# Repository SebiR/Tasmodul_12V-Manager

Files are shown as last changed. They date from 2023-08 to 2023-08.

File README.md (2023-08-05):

# 12V Power Management
A Tasmota compatible power selector for Caravans including automatic power source switching between on-board battery, car power and a mains PSU.
A INA226 measures the output voltage and current, the presence of the power sources are also available on GPIOs.

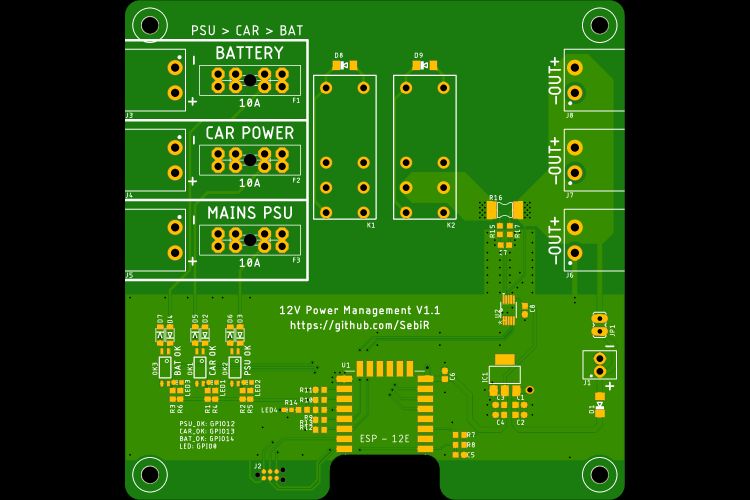
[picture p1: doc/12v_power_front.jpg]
12V Power


## Features
* Up to 15A (10A nom.)
* Fused inputs
* Current and voltage measurement
* Automatic source switching with priorities (hard-wired)

## Tasmota Configuration
Tasmota won't probe the INA226 unless full-scale current and the value of the shunt resistor are set.
 
`Sensor54 10 Return channel 1 shunt resistance and full scale current`

`Sensor54 11 [shunt_resistance] Set INA226 channel 1 shunt resistance in ohms, floating point`

`Sensor54 12 [full_scale_current] Set INA226 channel 1 full scale current in amperes, floating point`

So with the `Sensor54` command, we can set the current and the resistance for our board:

`Sensor54 11 0.002`

`Sensor54 12 15`

After that, we can see the current and the voltage in Tasmota.

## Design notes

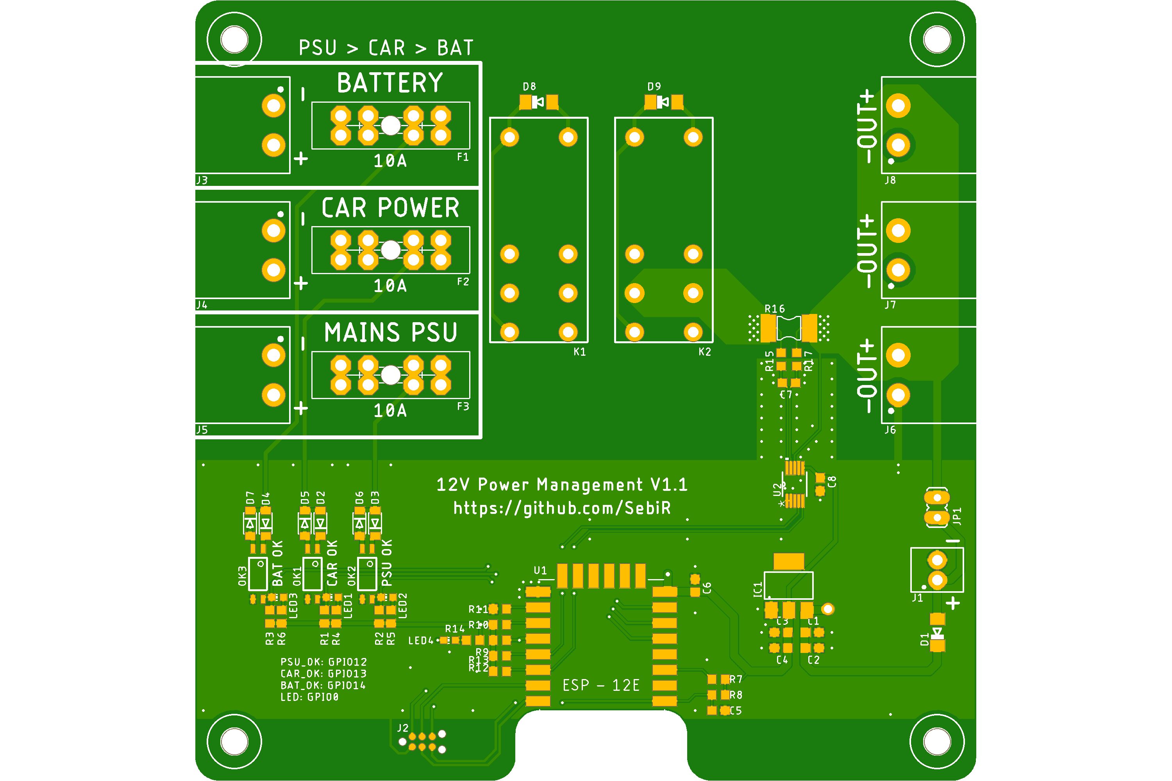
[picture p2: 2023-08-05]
doc/12v_power_front.png

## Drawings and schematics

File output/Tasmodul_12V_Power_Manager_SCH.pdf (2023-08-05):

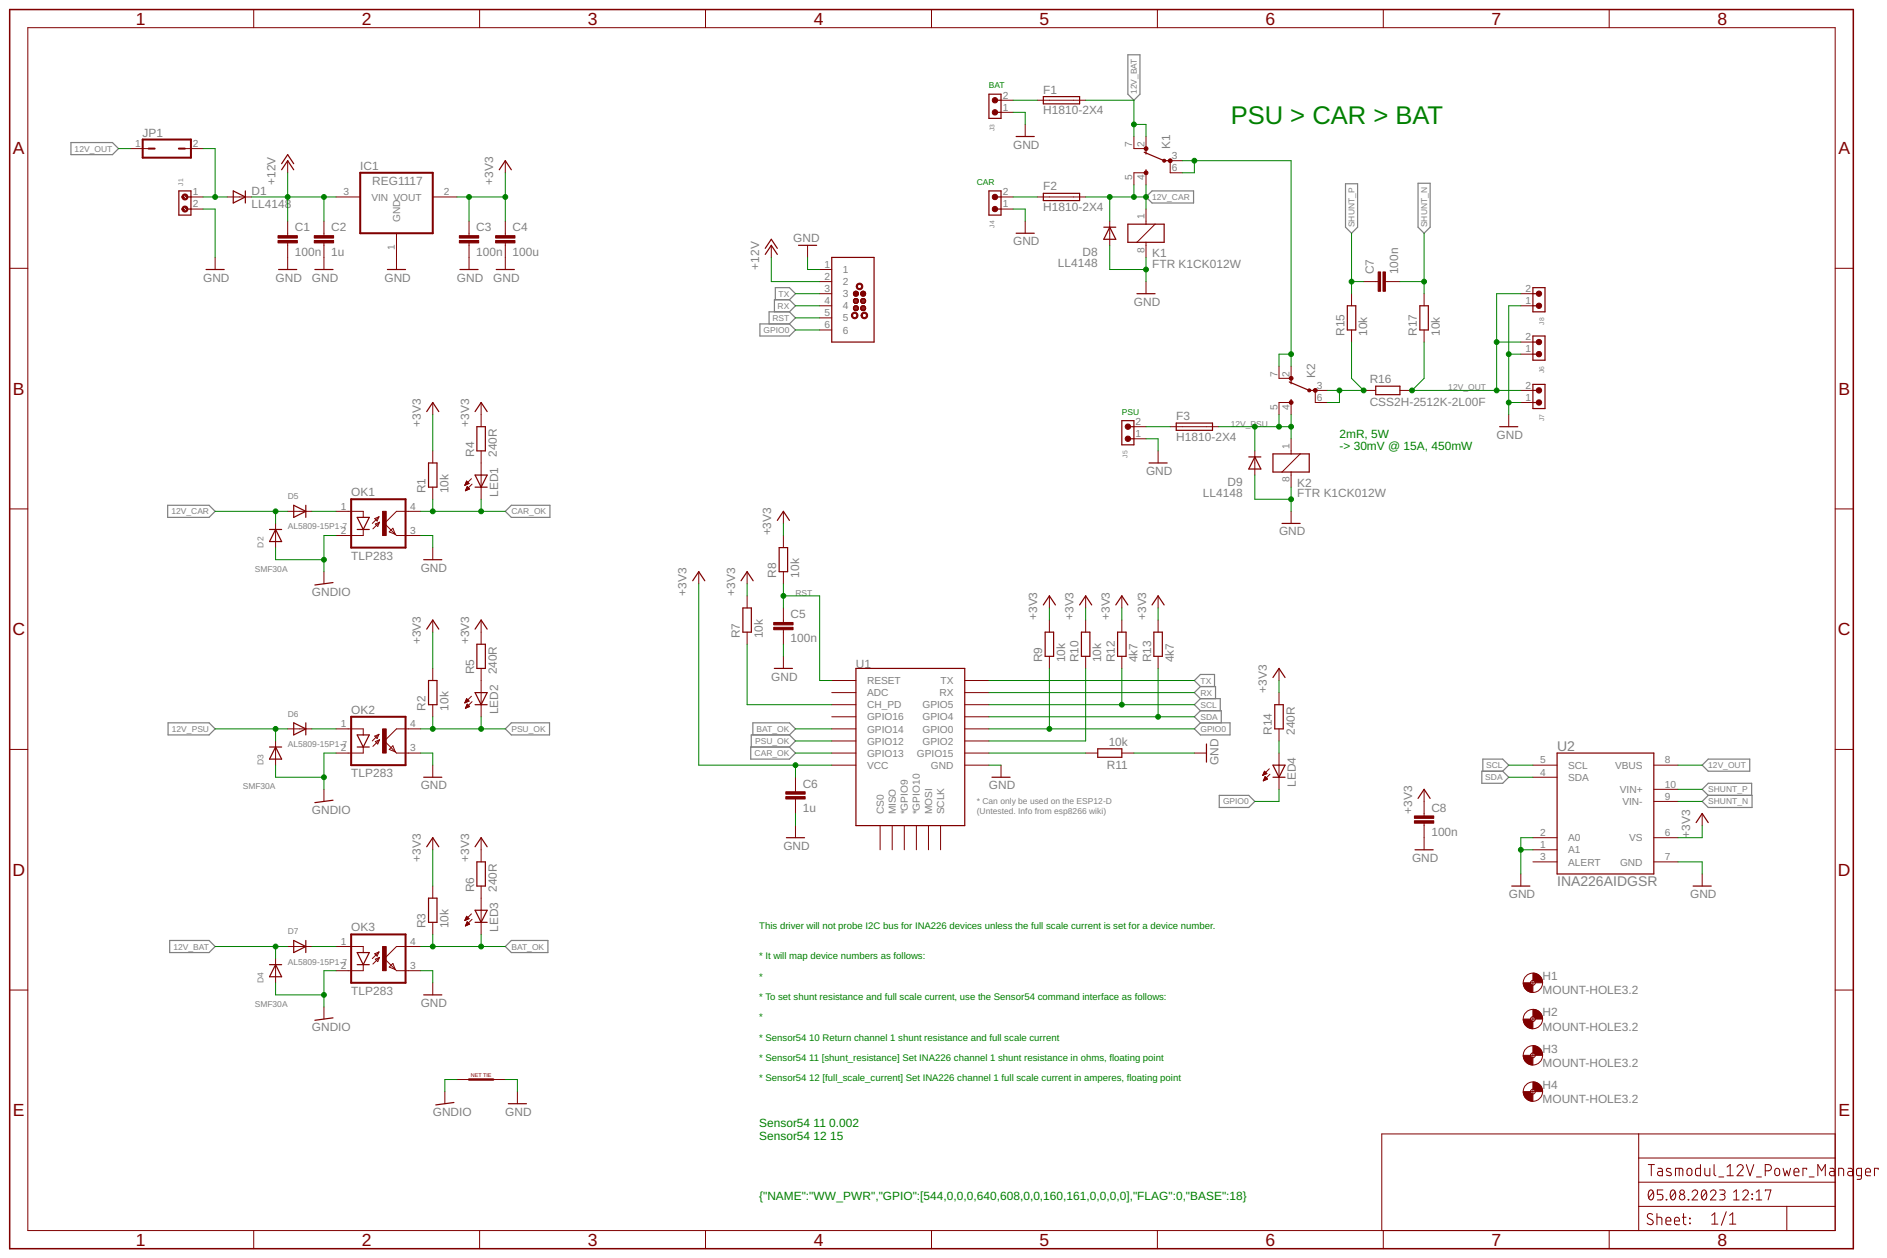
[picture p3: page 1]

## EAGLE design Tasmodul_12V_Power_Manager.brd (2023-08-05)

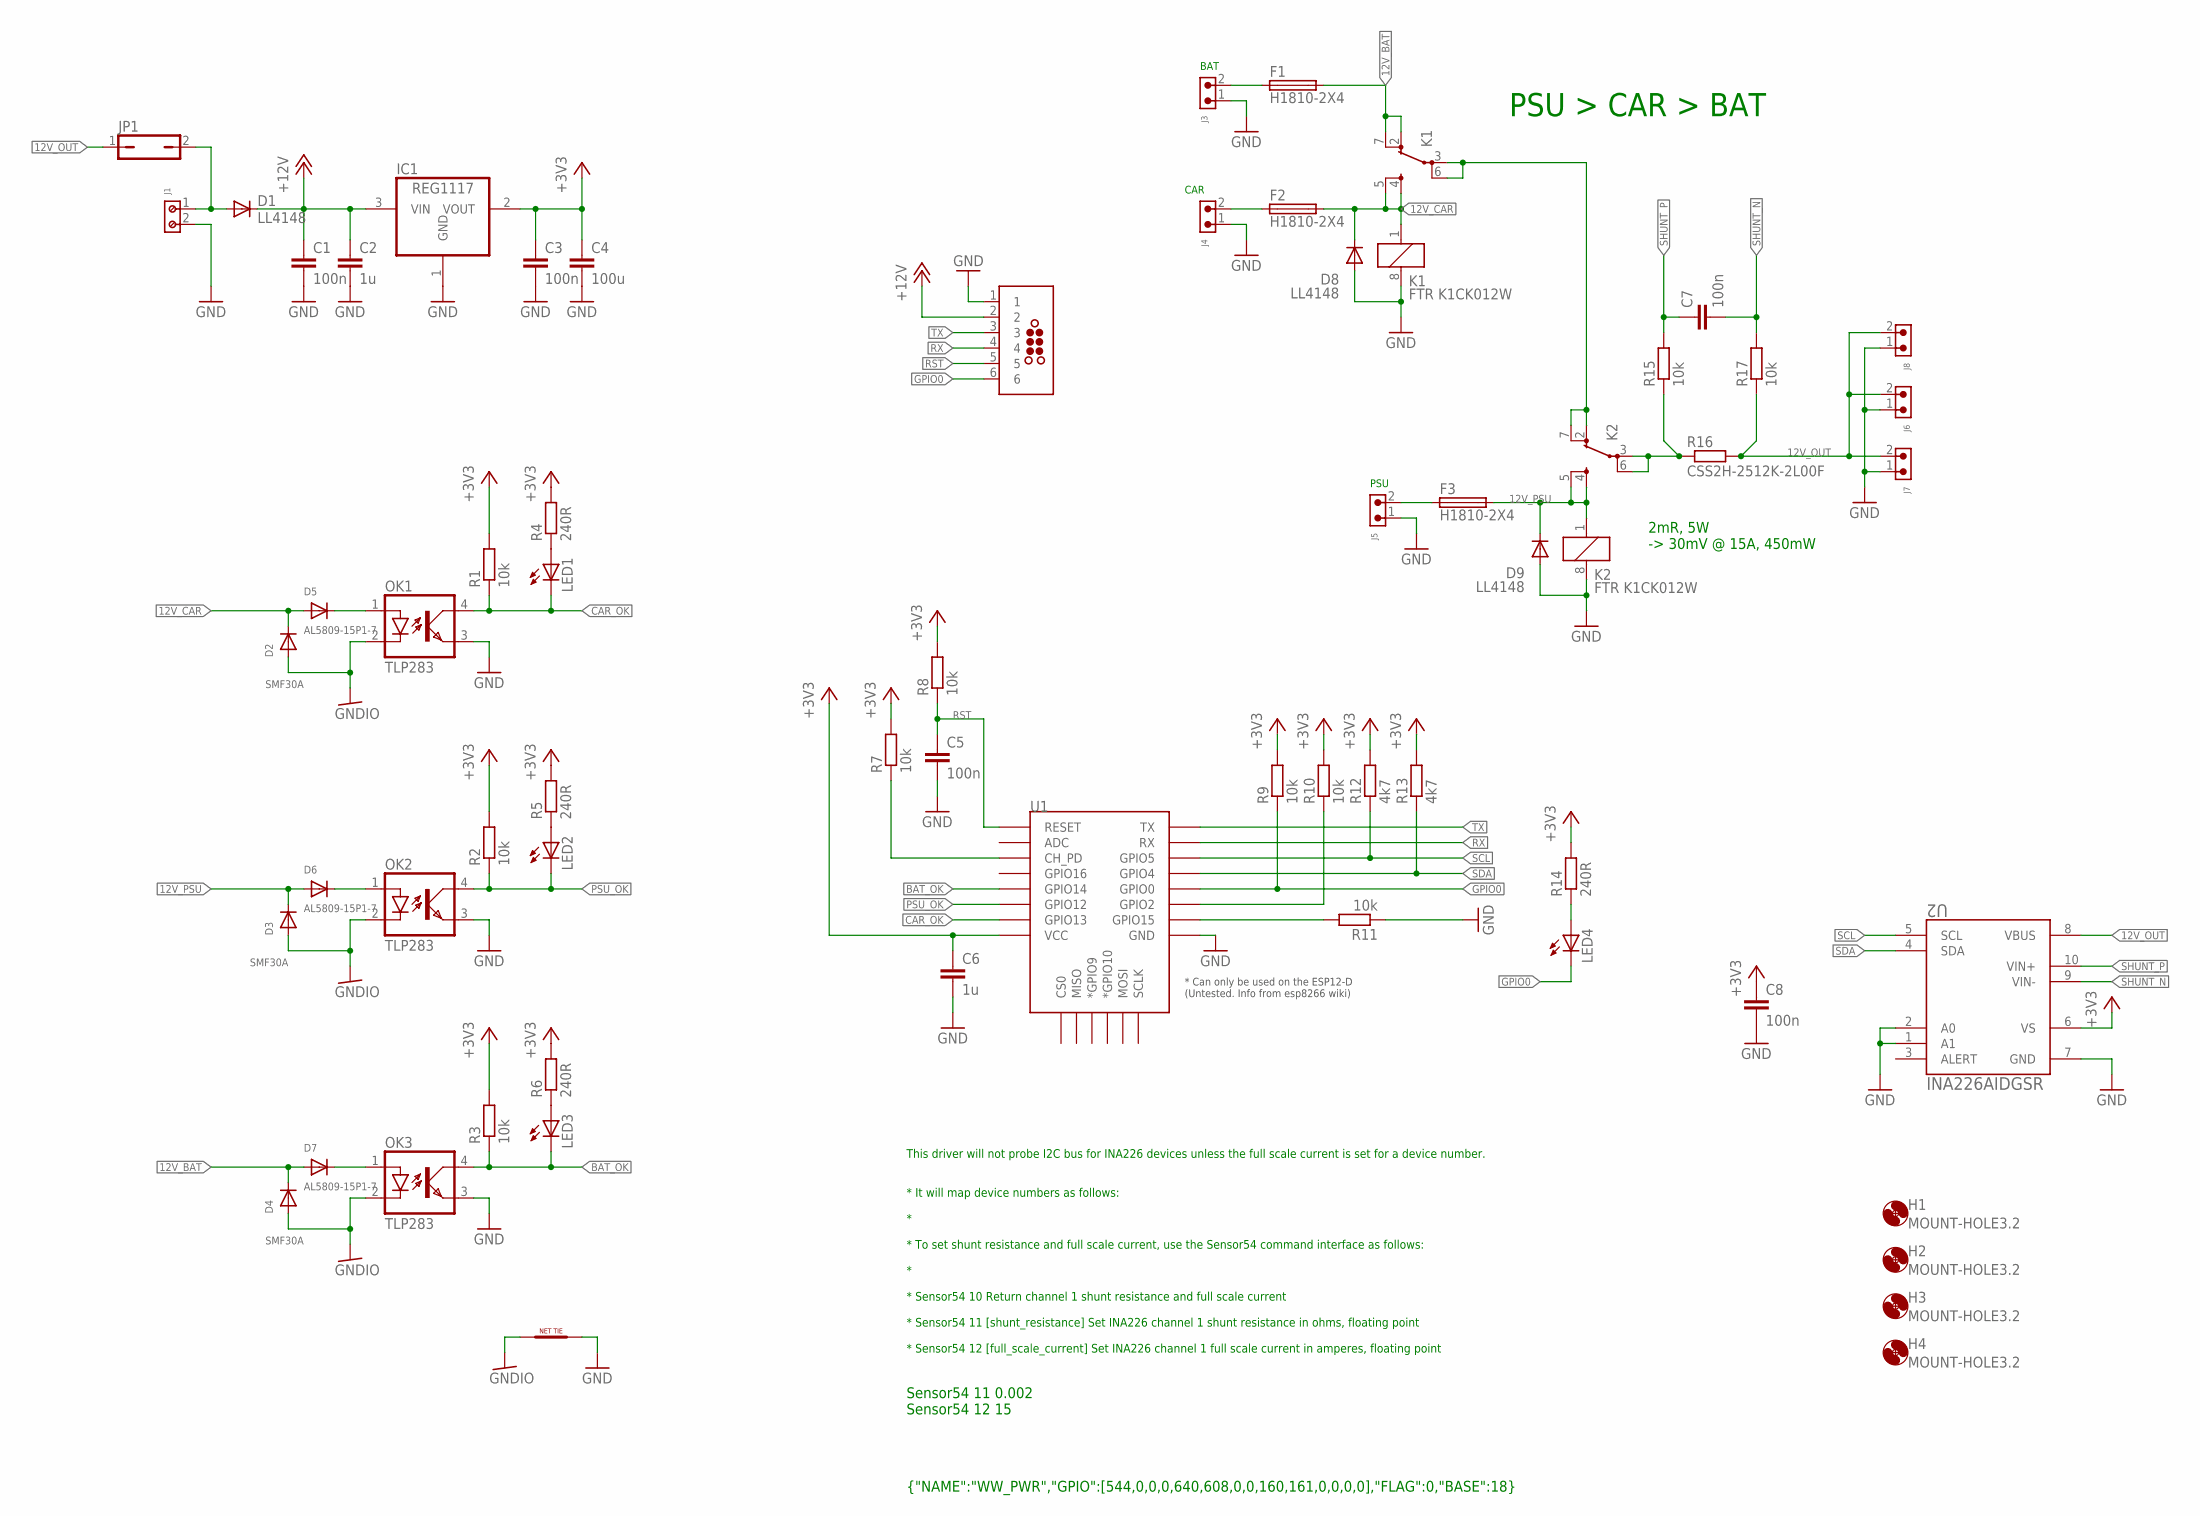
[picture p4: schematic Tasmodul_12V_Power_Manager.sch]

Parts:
C1, C3, C5, C7, C8: 100n; C0603
C2, C6: 1u; C0603
C4: 100u; C0603
D1, D8, D9: LL4148; MINIMELF
D2, D3, D4: SMF30A; SOD-123FL
D5, D6, D7: AL5809-15P1-7; SOD-123FL
F1, F2, F3: H1810-2X4
H1, H2, H3, H4: MOUNT-HOLE3.2; 3,2
IC1: REG1117; SOT223
J1: 691210910002
J2: TC2030-MCP-NL
J3, J4, J5, J6, J7, J8: 691313510002
JP1: JP1Q; JP1
K1, K2: FTR K1CK012W; FTR-K1C
LED1, LED2, LED3, LED4: LEDCHIP-LED0603; CHIP-LED0603
NT1: NET_TIE0.5MM; NET_TIE_0.5
OK1, OK2, OK3: TLP283; MINI-FLAT-4
R1, R2, R3, R7, R8, R9, R10, R11, R15, R17: 10k; R0603
R4, R5, R6, R14: 240R; R0603
R12, R13: 4k7; R0603
R16: CSS2H-2512K-2L00F
U1: ESP12ESMD; ESP12E-SMD
U2: INA226AIDGSR; DGS10

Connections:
12V_BAT: D4.C, D7.A, F1.B1 (2), F1.B2 (2), F1.B3 (2), F1.B4 (2), K1.2 (OA), K1.7 (OB)
12V_CAR: D2.C, D5.A, D8.C, F2.B1 (2), F2.B2 (2), F2.B3 (2), F2.B4 (2), K1.1, K1.4 (SA), K1.5 (SB)
12V_OUT: J6.2, J7.2, J8.2, JP1.1, R16.2, R17.1, U2.8 (VBUS)
12V_PSU: D3.C, D6.A, D9.C, F3.B1 (2), F3.B2 (2), F3.B3 (2), F3.B4 (2), K2.1, K2.4 (SA), K2.5 (SB)
+3V3: C3.1, C4.1, C6.1, C8.1, IC1.2 (VOUT), R1.2, R2.2, R3.2, R4.2, R5.2, R6.2, R7.2, R8.2, R9.2, R10.2, R12.2, R13.2, R14.2, U1.VCC, U2.6 (VS)
+12V: C1.1, C2.1, D1.C, IC1.3 (VIN), J2.2
BAT_OK: LED3.C, OK3.4 (COL), R3.1, U1.GPIO14
CAR_OK: LED1.C, OK1.4 (COL), R1.1, U1.GPIO13
GND: C1.2, C2.2, C3.2, C4.2, C5.2, C6.2, C8.2, D8.A, D9.A, IC1.1 (GND), J1.2, J2.1, J3.1, J4.1, J5.1, J6.1, J7.1, J8.1, K1.8 (2), K2.8 (2), NT1.NET2, OK1.3 (EMIT), OK2.3 (EMIT), OK3.3 (EMIT), R11.1, U1.GND, U2.1 (A1), U2.2 (A0), U2.7 (GND)
GNDIO: D2.A, D3.A, D4.A, NT1.NET1, OK1.2 (C), OK2.2 (C), OK3.2 (C)
GPIO0: J2.6, LED4.C, R9.1, U1.GPIO0
unnamed: LED1.A, R4.1
unnamed: F1.A1 (1), F1.A2 (1), F1.A3 (1), F1.A4 (1), J3.2
unnamed: D1.A, J1.1, JP1.2
unnamed: LED2.A, R5.1
unnamed: F3.A1 (1), F3.A2 (1), F3.A3 (1), F3.A4 (1), J5.2
unnamed: R7.1, U1.CH_PD
unnamed: R11.2, U1.GPIO15
unnamed: R10.1, U1.GPIO2
unnamed: LED4.A, R14.1
unnamed: LED3.A, R6.1
unnamed: K2.3 (PA), K2.6 (PB), R15.1, R16.1
unnamed: D5.C, OK1.1 (A)
unnamed: K1.3 (PA), K1.6 (PB), K2.2 (OA), K2.7 (OB)
unnamed: F2.A1 (1), F2.A2 (1), F2.A3 (1), F2.A4 (1), J4.2
unnamed: D6.C, OK2.1 (A)
unnamed: D7.C, OK3.1 (A)
PSU_OK: LED2.C, OK2.4 (COL), R2.1, U1.GPIO12
RST: C5.1, J2.5, R8.1, U1.RESET
RX: J2.4, U1.RXD0 (RX)
SCL: R12.1, U1.GPIO5, U2.5 (SCL)
SDA: R13.1, U1.GPIO4, U2.4 (SDA)
SHUNT_N: C7.2, R17.2, U2.9 (VIN-)
SHUNT_P: C7.1, R15.2, U2.10 (VIN+)
TX: J2.3, U1.TXD0 (TX)

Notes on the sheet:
BAT
PSU
This driver will not probe I2C bus for INA226 devices unless the full scale current is set for a device number. * It will map device numbers as follows: * * To set shunt resistance and full scale current, use the Sensor54 command interface as follows: * * Sensor54 10 Return channel 1 shunt resistan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
{"NAME":"WW_PWR","GPIO":[544,0,0,0,640,608,0,0,160,161,0,0,0,0],"FLAG":0,"BASE":18}
Sensor54 11 0.002 Sensor54 12 15
PSU > CAR > BAT
CAR
2mR, 5W -> 30mV @ 15A, 450mW

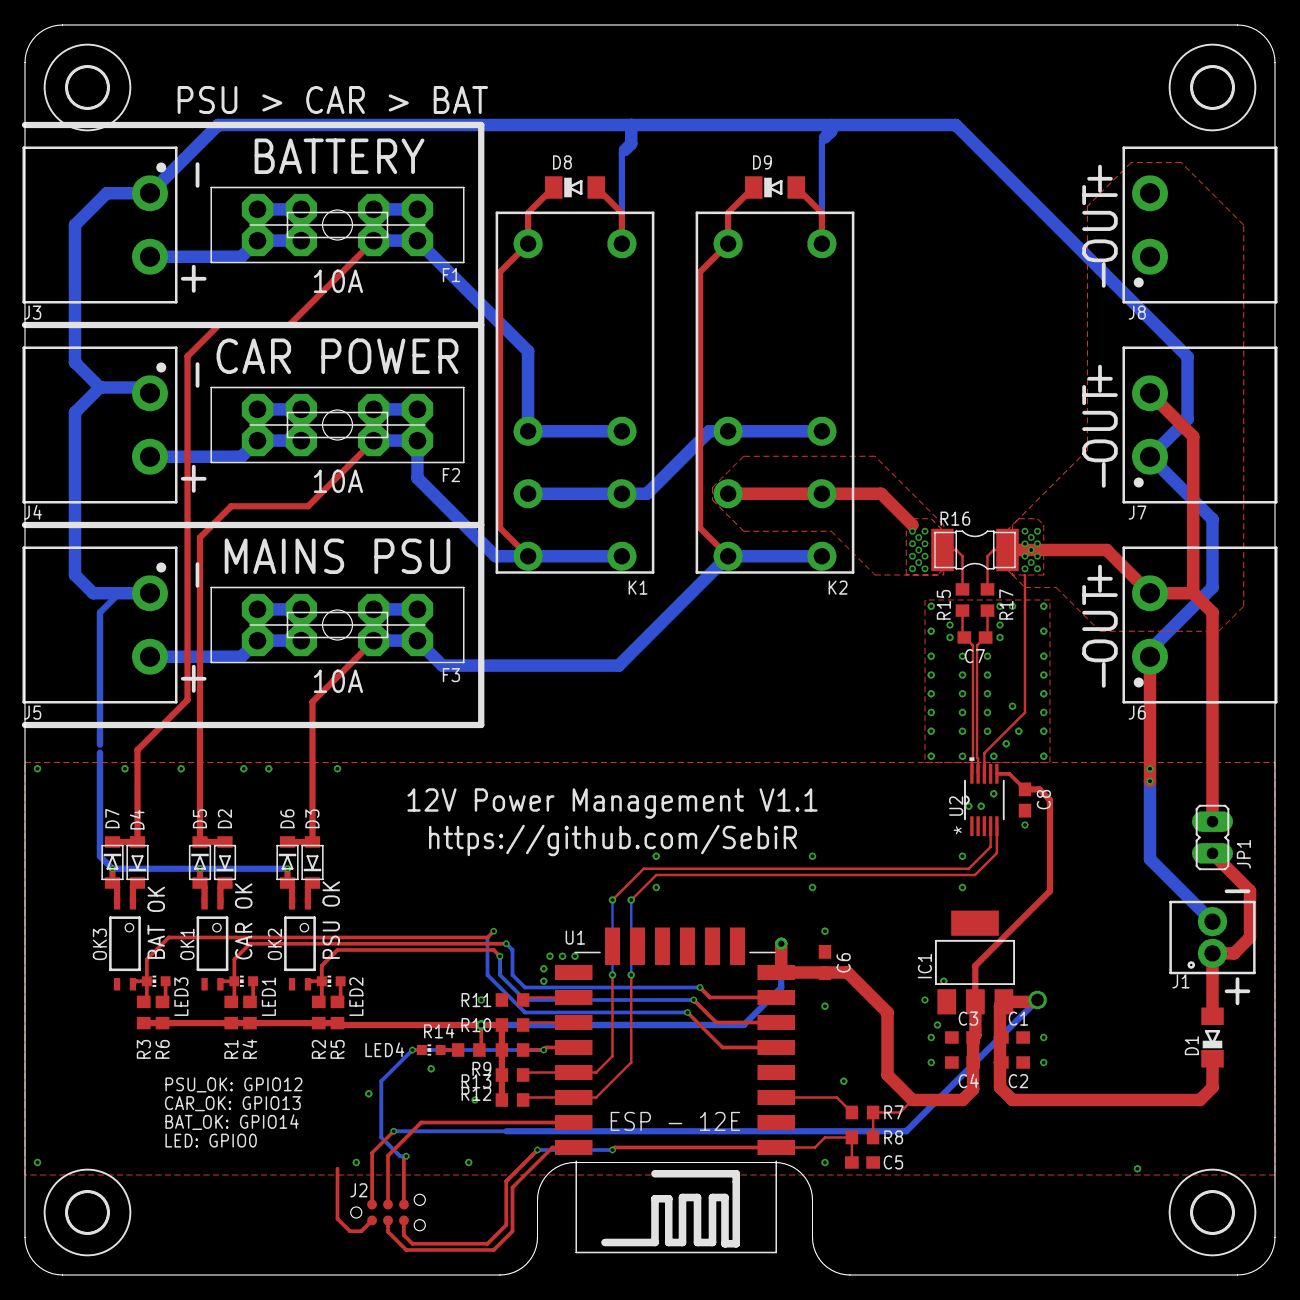
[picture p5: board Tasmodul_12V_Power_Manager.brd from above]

Board: 2 copper layers, 100.0 x 100.0 mm, 63 parts (1 on the bottom side), 35 nets.

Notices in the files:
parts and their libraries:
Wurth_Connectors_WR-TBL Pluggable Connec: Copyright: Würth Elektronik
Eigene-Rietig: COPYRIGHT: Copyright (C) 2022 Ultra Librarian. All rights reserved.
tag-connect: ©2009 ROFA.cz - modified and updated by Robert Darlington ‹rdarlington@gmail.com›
